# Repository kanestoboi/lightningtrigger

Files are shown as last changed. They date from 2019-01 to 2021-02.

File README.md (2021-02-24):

# Lightning Trigger

Features
* Lightning Triggering - By using a photo transistor, lightning strikes are detected and triggers the camera at the same instant.  
  
* Sound Triggering - Sound triggering mode is used to capture sound events such as water droplets, breaking glass, and fireworks.  
  
* Timelapse- Calculates the number of photos for a given length timelapse, given the photo duration, interval, and total timelapse length before taking all the required photos.  
  
Currently has support for two triggering outputs (can trigger two devices at once) with an additional two outputs being added in the next revision.  
  
Control is through an Android app using the HM-11 Bluetooth module.  
  
Power is from a li-po battery and is charged using an onboard li-po charger.

## Images

Images are located in the [Images](https://github.com/kanestoboi/lightningtrigger/tree/master/Images) directory.

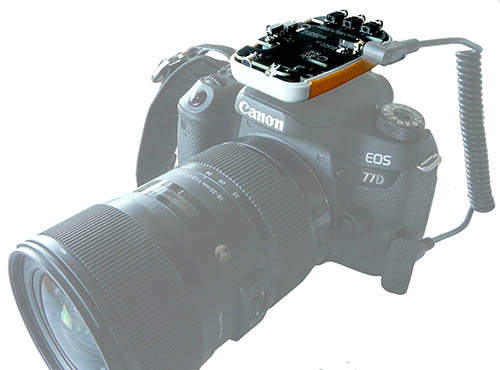
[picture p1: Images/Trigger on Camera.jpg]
Trigger with Camera


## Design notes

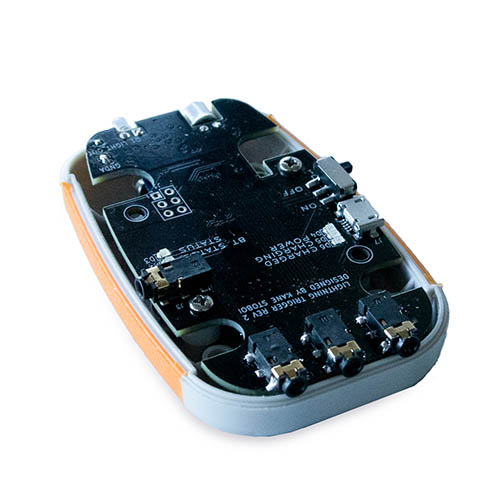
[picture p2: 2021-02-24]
Images/Trigger 2.jpg

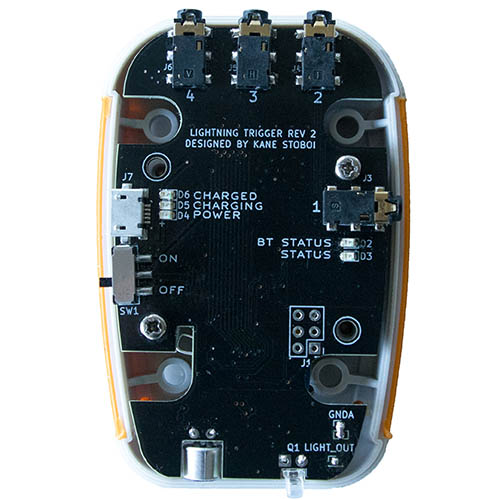
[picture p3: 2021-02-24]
Images/Trigger 1.jpg

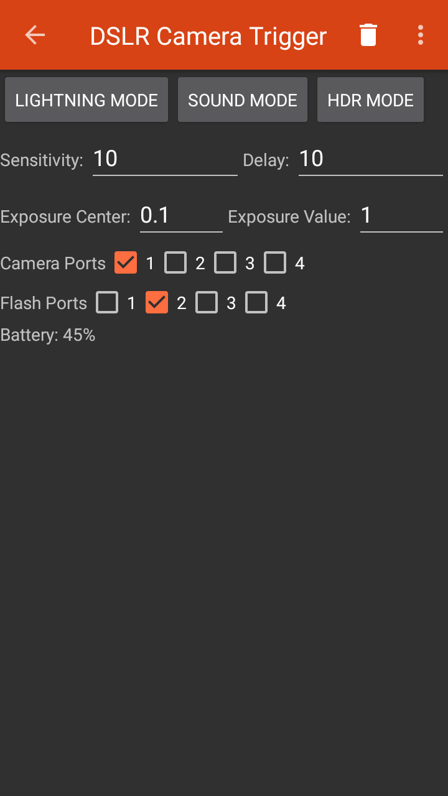
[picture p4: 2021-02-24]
Images/mobile app.png

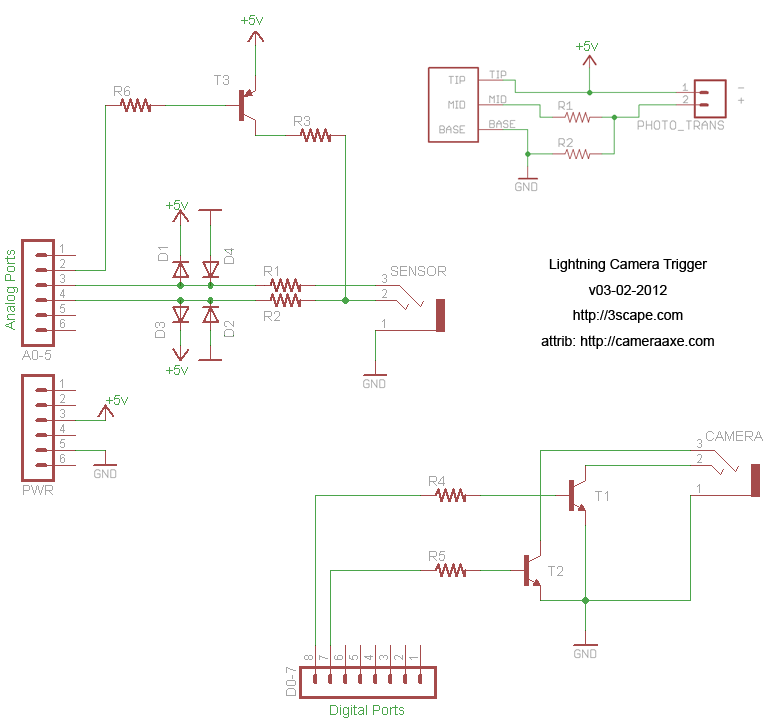
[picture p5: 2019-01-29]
Reference/circuit.png

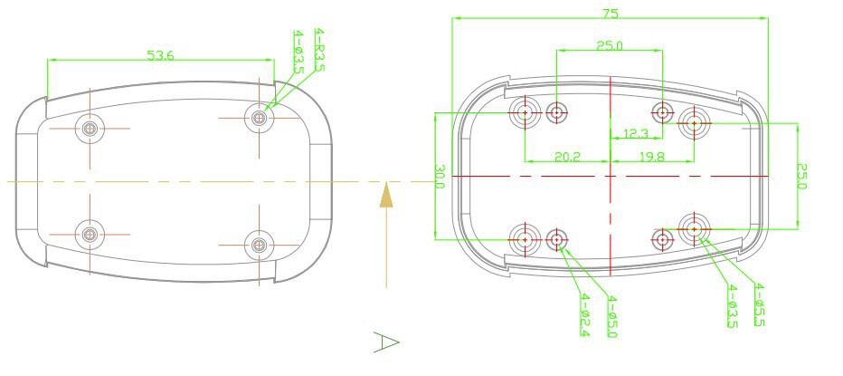
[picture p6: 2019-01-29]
Reference/Drawing1.jpg

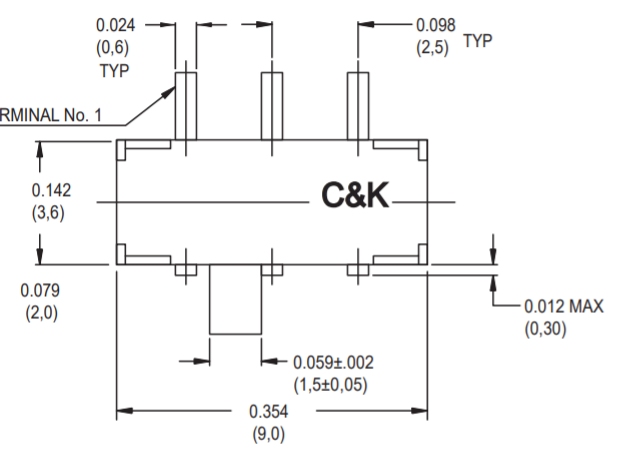
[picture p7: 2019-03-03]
Reference/switch.PNG

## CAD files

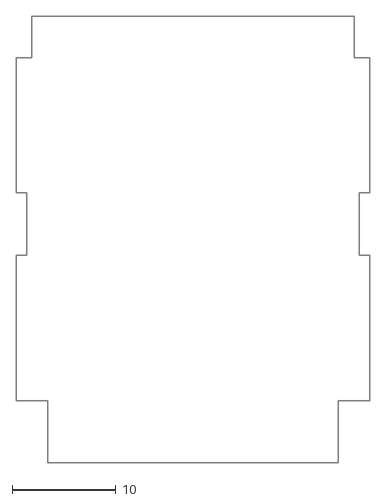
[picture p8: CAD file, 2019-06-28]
Hardware/lightning trigger Rev 3/board outline 2.dxf
34.0 x 43.0

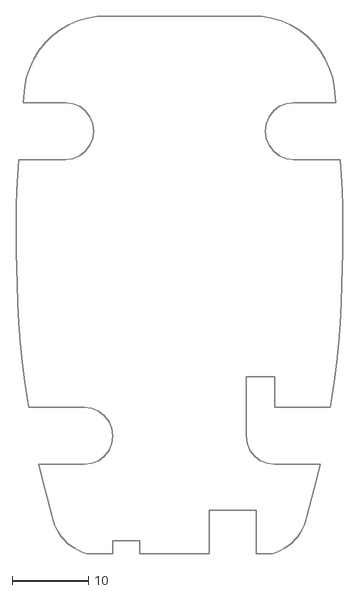
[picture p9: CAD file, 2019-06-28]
Reference/board edge cuts rev 2.dxf
42.9 x 70.5

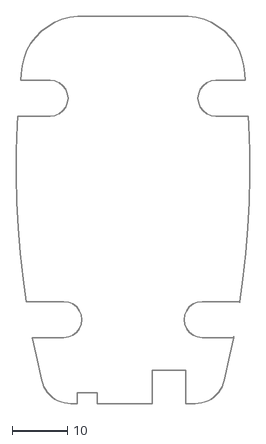
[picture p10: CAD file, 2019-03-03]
Hardware/lightning trigger Rev 3/board image.dxf
42.2 x 70.0

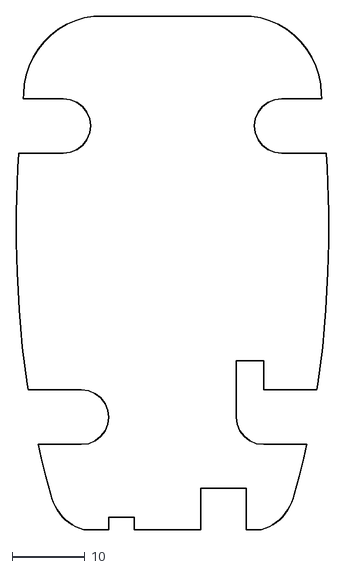
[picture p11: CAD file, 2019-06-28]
Reference/board edge cuts rev 2 R12.dxf
42.9 x 70.5

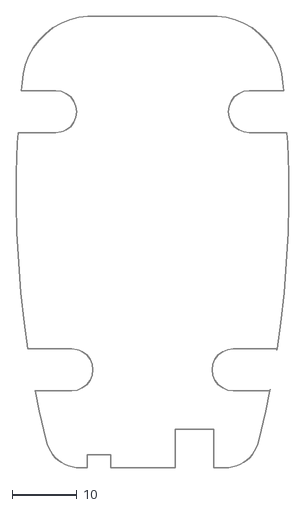
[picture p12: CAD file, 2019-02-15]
Hardware/lightning trigger Rev 3/board outline.dxf
42.2 x 70.0

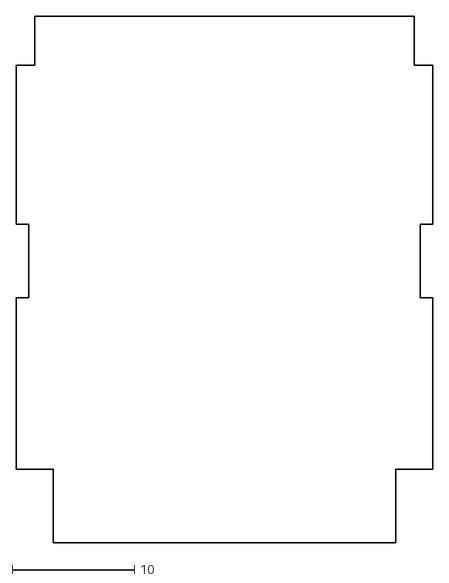
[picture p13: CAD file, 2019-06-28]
Reference/board outline R12.dxf
34.0 x 43.0

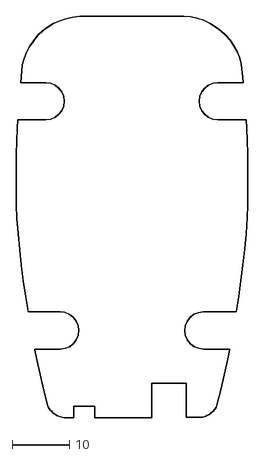
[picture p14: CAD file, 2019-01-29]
Hardware/lightning trigger Rev 3/board outline libreCAD.dxf
40.5 x 70.0

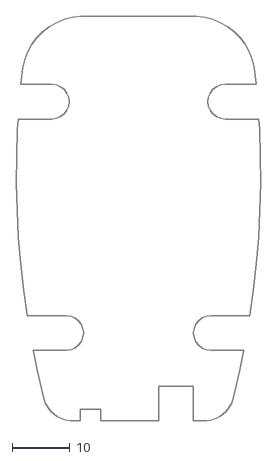
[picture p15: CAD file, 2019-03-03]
Reference/board image.dxf
42.2 x 70.0

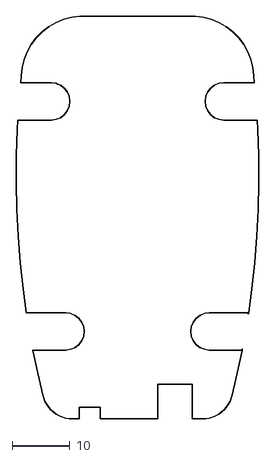
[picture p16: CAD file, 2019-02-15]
Reference/enclosure outline LibreCAD.dxf
42.2 x 70.0

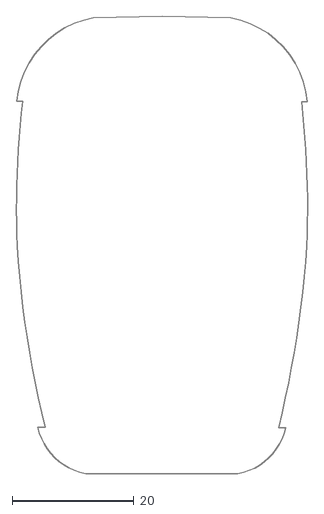
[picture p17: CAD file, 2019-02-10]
Reference/enclosure outline.dxf
47.8 x 75.0

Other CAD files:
Reference/board image.skp

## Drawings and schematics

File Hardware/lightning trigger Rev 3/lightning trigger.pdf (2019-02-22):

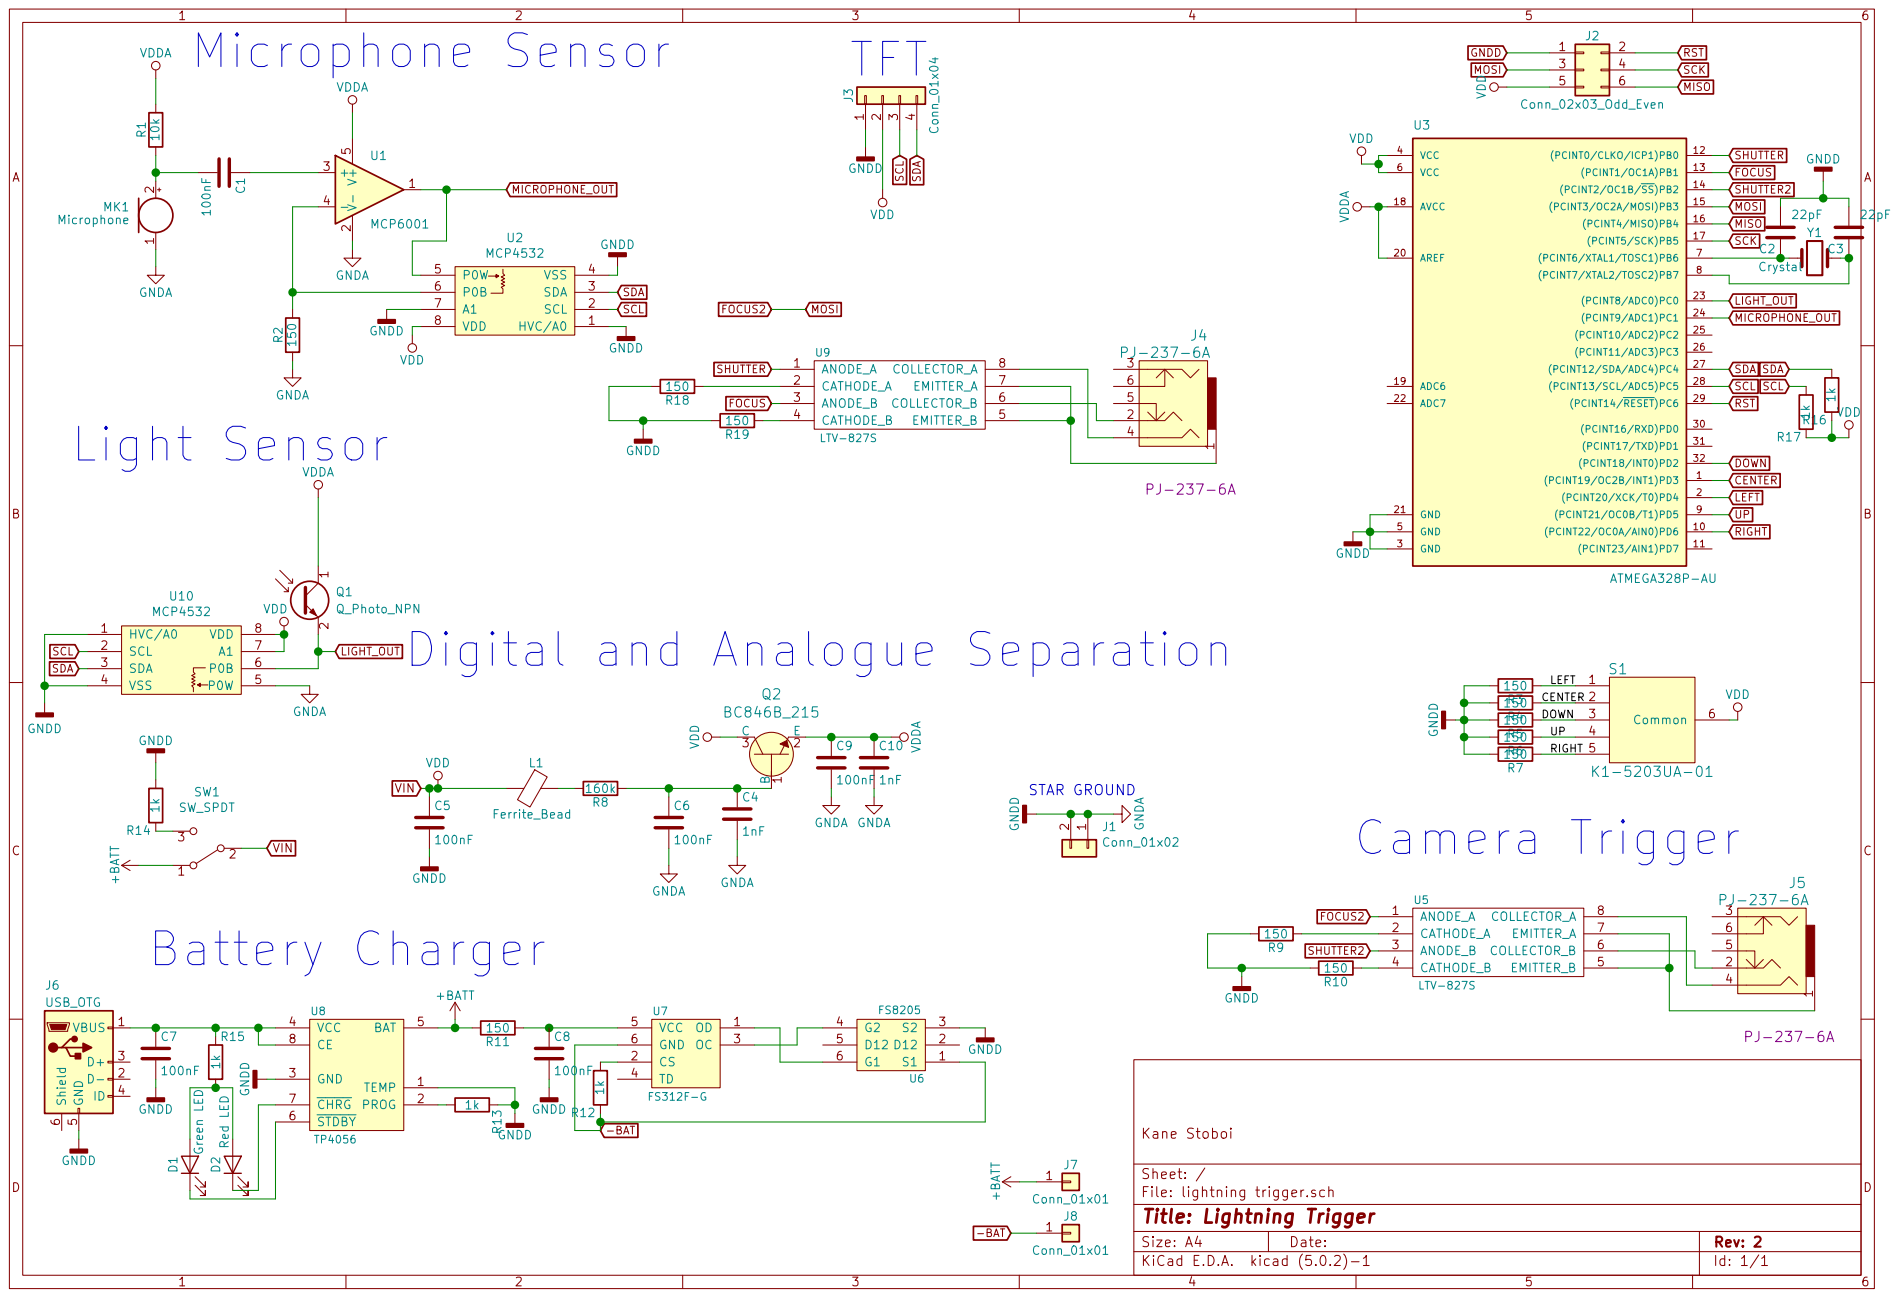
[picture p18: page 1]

LEFT RIGHT CENTER TFT

4 J3 Conn_01x04 GNDD SCL SDA GNDD

1 2 Q1Q_Photo_NPN
Digital and Analogue Separation VDD

File: lightning trigger.sch Sheet: / Kane Stoboi

Id: 1/1 Title: Lightning Trigger

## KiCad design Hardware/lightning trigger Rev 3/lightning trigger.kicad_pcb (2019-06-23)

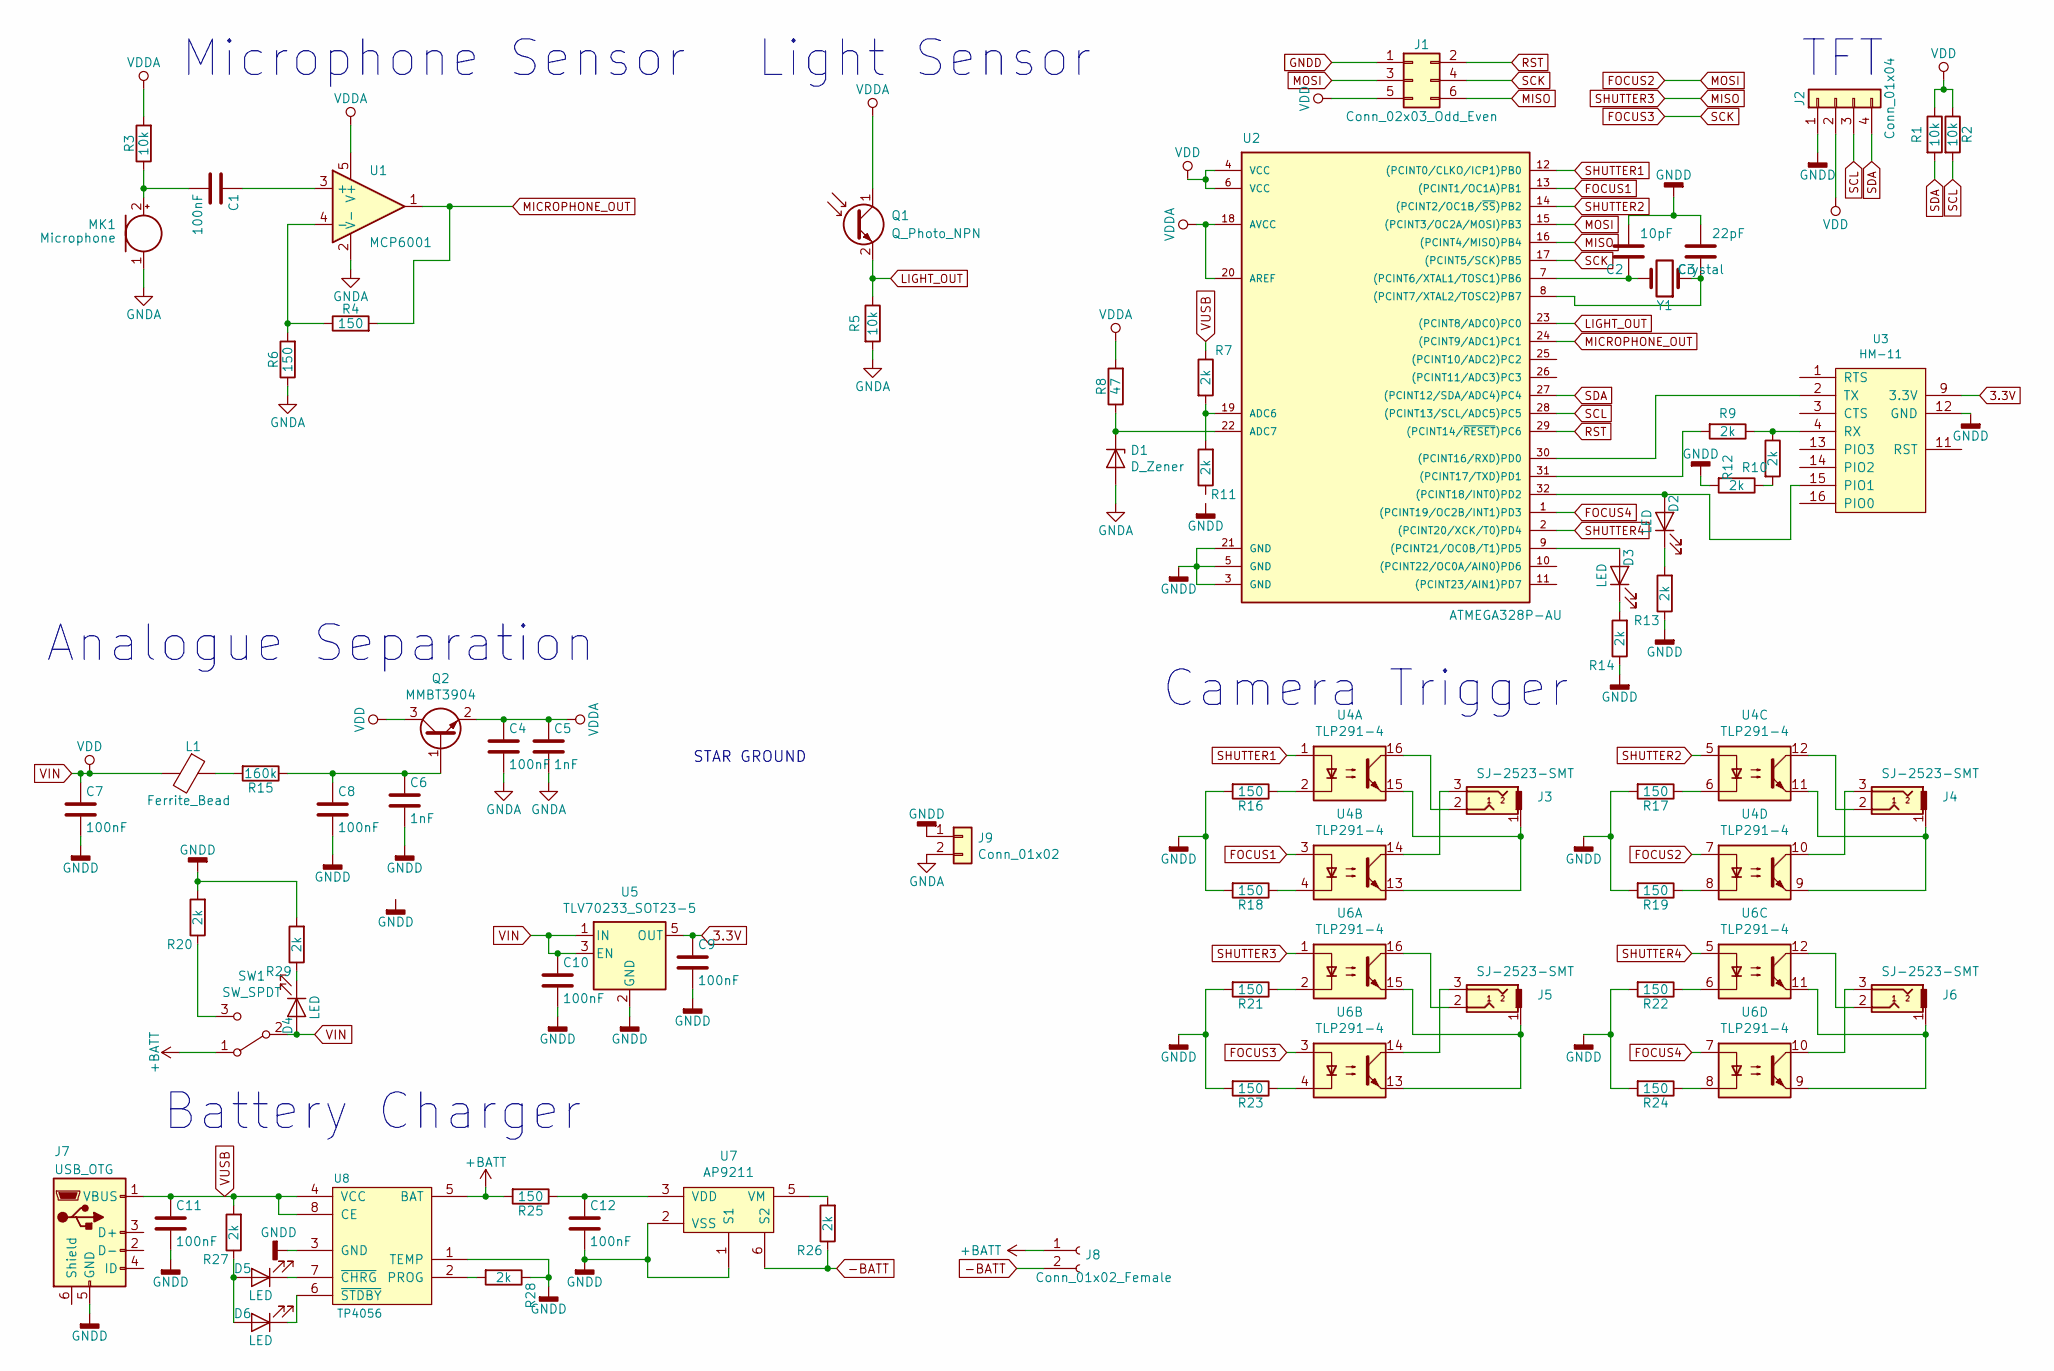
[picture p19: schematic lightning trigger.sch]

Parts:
C1, C4, C7, C8, C9, C10, C11, C12: 100nF; C_0603_1608Metric; Manufacturer Part Number C0603C104J5RACTU
C2: 10pF; C_0603_1608Metric; Manufacturer Part Number CGA3E2C0G1H100D080AA
C3: 22pF; C_0603_1608Metric; Manufacturer Part Number CGA3E2C0G1H100D080AA
C5, C6: 1nF; C_0603_1608Metric; Manufacturer Part Number C0603C102J1RACTU
D1: D_Zener; SC-90A; Manufacturer Part Number DZ2J027M0L
D2, D3, D4, D6: LED; LED_0603_1608Metric; Manufacturer Part Number LTST-C190KGKT
D5: LED; LED_0603_1608Metric; Manufacturer Part Number LTST-C190KRKT
J1: Conn_02x03_Odd_Even; Pin_Header_Straight_2x03_Pitch2.54mm
J2: Conn_01x04; Pin_Header_Straight_1x04_Pitch2.54mm
J3, J4, J5, J6: SJ-2523-SMT; Manufacturer Part Number SJ-2523-SMT
J7: USB_OTG; USB_Micro_C77238
J8: Conn_01x02_Female; JST_PH_S2B-PH-SM4-TB_1x02-1MP_P2.00mm_Horizontal; Manufacturer Part Number S2B-PH-SM4-TB
J9: Conn_01x02; R_0805_2012Metric
L1: Ferrite_Bead; C_0805_2012Metric; Manufacturer Part Number MH2029-300Y
MK1: Microphone; ELECTRET MICROPHONE
Q1: Q_Photo_NPN; LED_D3.0mm_Horizontal_O1.27mm_Z2.0mm; Manufacturer Part Number SFH 310-2/3
Q2: MMBT3904; SOT-23; Manufacturer Part Number MMBT3904LT1G
R1, R2, R3, R5: 10k; R_0603_1608Metric; Manufacturer Part Number ERJ-3GEYJ103V
R4, R6, R16, R17, R18, R19, R21, R22, R23, R24, R25: 150; R_0603_1608Metric; Manufacturer Part Number ERJ-3GEYJ151V
R7, R9, R10, R11, R12, R13, R14, R20, R26, R27, R28, R29: 2k; R_0603_1608Metric; Manufacturer Part Number ERJ-3GEYJ202V
R8: 47; R_0603_1608Metric; Manufacturer Part Number ERJ-3GEYJ470V
R15: 160k; R_0603_1608Metric; Manufacturer Part Number ERJ-3GEYJ164V
SW1: SW_SPDT; JS102011SAQN; Manufacturer Part Number JS102011SAQN
U1: MCP6001; SOT-23-5; Manufacturer Part Number MCP6001T-I/OT
U2: ATMEGA328P-AU; TQFP-32_7x7mm_Pitch0.8mm; Manufacturer Part Number ATMEGA328P-AU
U3: HM-11; Manufacturer Part Number HM-11
U4, U6: TLP291-4; SOIC-16_4.55x10.3mm_P1.27mm; Manufacturer Part Number TLP291-4(GB-TP,E)
U5: TLV70233_SOT23-5; SOT-23-5; Manufacturer Part Number TLV70233DBVR
U7: AP9211; U-DFN2030-6; Manufacturer Part Number AP9211S-AN-HAC-7
U8: TP4056; SOP-8; Manufacturer Part Number DIO5158
Y1: Crystal; Crystal_SMD_2016-4Pin_2.0x1.6mm; Manufacturer Part Number ECS-160-10-37-JTN-TR

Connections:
3.3V: C9.1, U3.9 (3.3V), U5.5 (OUT)
+BATT: J8.1, R25.2, SW1.1 (A), U8.5 (BAT)
-BATT: J8.2, R26.1, U7.6 (S2)
FOCUS1: U2.13 ((PCINT1/OC1A)PB1), U4.3
FOCUS2: J1.3, U2.15 ((PCINT3/OC2A/MOSI)PB3), U4.7
FOCUS3: J1.4, U2.17 ((PCINT5/SCK)PB5), U6.3
FOCUS4: U2.1 ((PCINT19/OC2B/INT1)PD3), U6.7
GNDA: C4.2, C5.2, D1.2 (A), J9.2, MK1.1 (-), R5.2, R6.1, U1.2 (V-); also elsewhere on the board
GNDD: C2.2, C3.2, C6.2, C7.2, C8.2, C9.2, C10.2, C11.2, C12.2, J1.1, J2.1, J7.5 (GND), J9.1, R12.2, R13.1, R14.1, R16.2, R17.2, R18.2, R19.2, R20.2, R21.2, R22.2, R23.2, R24.2, R28.1, R29.2, U2.3 (GND), U2.5 (GND), U2.21 (GND), U3.12 (GND), U5.2 (GND), U7.1 (S1), U7.2 (VSS), U8.1 (TEMP), U8.3 (GND)
LIGHT_OUT: Q1.2 (E), R5.1, U2.23 ((PCINT8/ADC0)PC0); also elsewhere on the board
MICROPHONE_OUT: R4.2, U1.1, U2.24 ((PCINT9/ADC1)PC1)
MISO: J1.6, U2.16 ((PCINT4/MISO)PB4), U6.1
unnamed: C1.1, U1.3 (+)
unnamed: C1.2, MK1.2 (+), R3.1
unnamed: C2.1, U2.7 ((PCINT6/XTAL1/TOSC1)PB6), Y1.2
unnamed: C3.1, U2.8 ((PCINT7/XTAL2/TOSC2)PB7), Y1.1
unnamed: C6.1, C8.1, Q2.1 (B), R15.1
unnamed: C12.1, R25.1, U7.3 (VDD)
unnamed: D1.1 (K), R8.1, U2.22 (ADC7)
unnamed: D2.1 (K), R13.2
unnamed: D2.2 (A), U2.32 ((PCINT18/INT0)PD2), U3.15 (PIO1)
unnamed: D3.1 (K), R14.2
unnamed: D3.2 (A), U2.9 ((PCINT21/OC0B/T1)PD5)
unnamed: D4.1 (K), R29.1
unnamed: D5.1 (K), U8.7 (~CHRG)
unnamed: D5.2 (A), D6.2 (A), R27.1
unnamed: D6.1 (K), U8.6 (~STDBY)
unnamed: J3.1, U4.13, U4.15
unnamed: J3.2, U4.16
unnamed: J3.3, U4.14
unnamed: J4.1, U4.9, U4.11
unnamed: J4.2, U4.12
unnamed: J4.3, U4.10
unnamed: J5.1, U6.13, U6.15
unnamed: J5.2, U6.16
unnamed: J5.3, U6.14
unnamed: J6.1, U6.9, U6.11
unnamed: J6.2, U6.12
unnamed: J6.3, U6.10
unnamed: L1.1, R15.2
unnamed: R4.1, R6.2, U1.4 (-)
unnamed: R9.2, U2.31 ((PCINT17/TXD)PD1)
unnamed: R9.1, R10.1, U3.4 (RX)
unnamed: R10.2, R12.1
unnamed: R7.2, R11.2, U2.19 (ADC6)
unnamed: R16.1, U4.2
unnamed: R17.1, U4.6
unnamed: R18.1, U4.4
unnamed: R19.1, U4.8
unnamed: R20.1, SW1.3 (C)
unnamed: R21.1, U6.2
unnamed: R22.1, U6.6
unnamed: R23.1, U6.4
unnamed: R24.1, U6.8
unnamed: R26.2, U7.5 (VM)
unnamed: R28.2, U8.2 (PROG)
unnamed: U2.30 ((PCINT16/RXD)PD0), U3.2 (TX)
RST: J1.2, U2.29 ((PCINT14/~RESET~)PC6)
SCL: J2.3, R2.2, U2.28 ((PCINT13/SCL/ADC5)PC5)
SDA: J2.4, R1.2, U2.27 ((PCINT12/SDA/ADC4)PC4)
SHUTTER1: U2.12 ((PCINT0/CLKO/ICP1)PB0), U4.1
SHUTTER2: U2.14 ((PCINT2/OC1B/~SS~)PB2), U4.5
SHUTTER4: U2.2 ((PCINT20/XCK/T0)PD4), U6.5
VDDA: C4.1, C5.1, Q1.1 (C), Q2.2 (E), R3.2, R8.2, U1.5 (V+), U2.18 (AVCC), U2.20 (AREF)
VIN: C7.1, C10.1, D4.2 (A), J1.5, J2.2, L1.2, Q2.3 (C), R1.1, R2.1, SW1.2 (B), U2.4 (VCC), U2.6 (VCC), U5.1 (IN), U5.3 (EN)
VUSB: C11.1, J7.1 (VBUS), R7.1, R27.2, U8.4 (VCC), U8.8 (CE)

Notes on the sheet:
Microphone Sensor
Light Sensor
Camera Trigger
TFT
Battery Charger
Analogue Separation
STAR GROUND

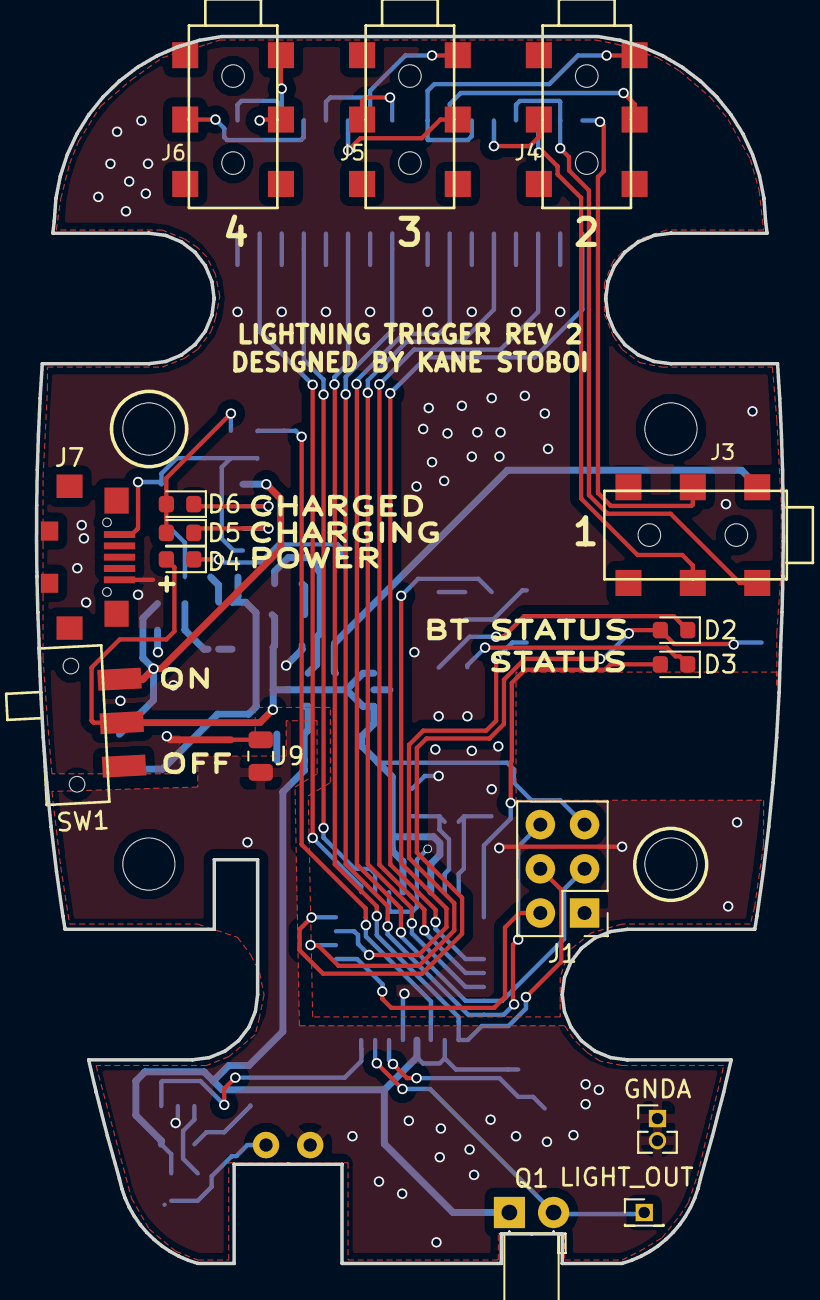
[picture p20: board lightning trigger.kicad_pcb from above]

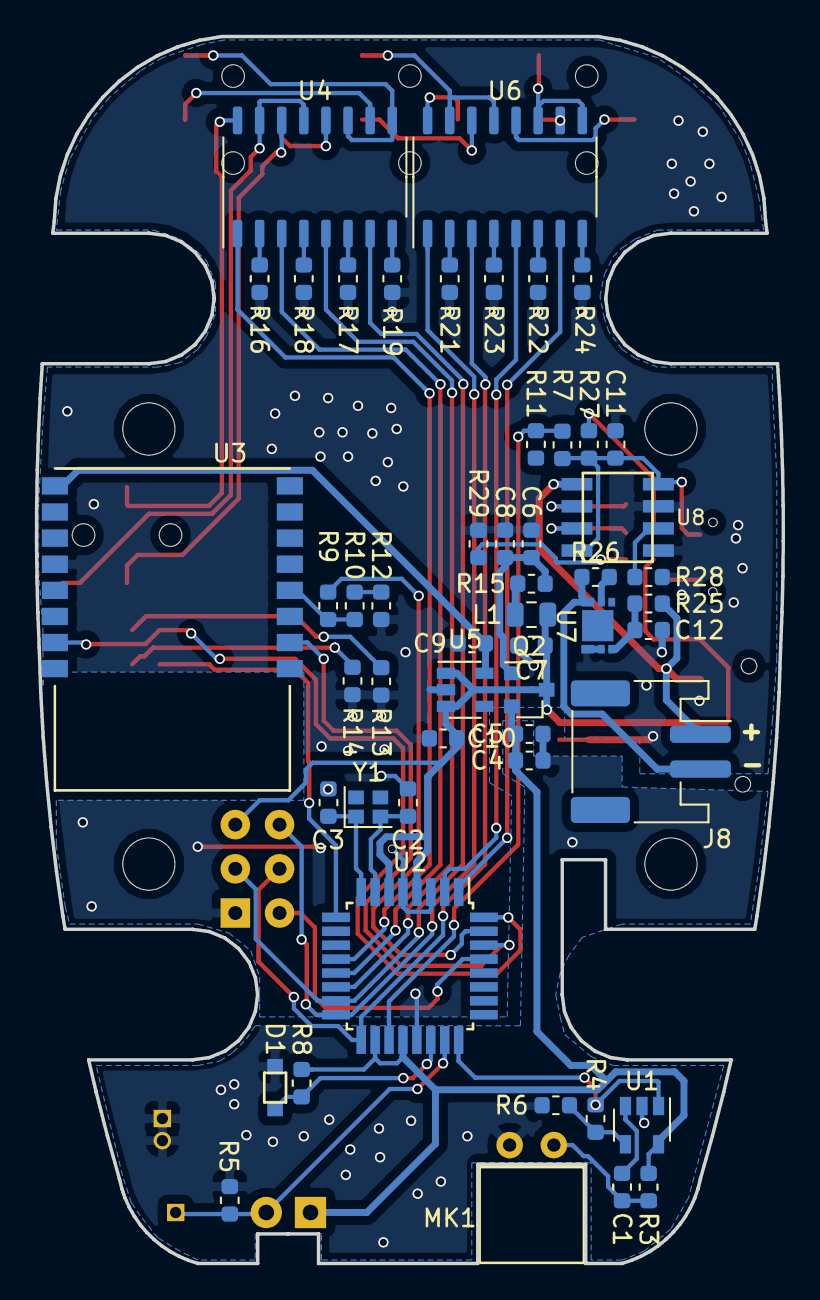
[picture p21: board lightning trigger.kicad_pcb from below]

Board: 2 copper layers, 42.9 x 70.5 mm, 68 parts (52 on the bottom side), 63 nets.

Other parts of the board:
GNDA: PinHeader_1x02_P1.27mm_Vertical
LIGHT_OUT: PinHeader_1x01_P1.27mm_Vertical

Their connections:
GNDA: GNDA.1, GNDA.2; also elsewhere on the board
LIGHT_OUT: LIGHT_OUT.1; also elsewhere on the board

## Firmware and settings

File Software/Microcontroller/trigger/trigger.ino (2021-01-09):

// Include libraries for LCD
#include <util/delay.h>


#include <SoftwareSerial.h>// import the serial library
#include <ArduinoJson.h>

#include "Timelapse.h"
#include "ThresholdTrigger.h"
#include "BatteryIndicator.h"
#include "HDR.h"


void triggerCamera();
void focusCamera();
void releaseCamera();
void triggerFlash();

volatile bool Serial_INTERRUPT_FLAG = false;
volatile bool BT_SEND_FLAG = false;

/*********************************
 * DEVELOPMENT SETUP
 ********************************/

int rx = 0;  // software serial RX pin
int tx = 1;  // software serial TX pin 
long counter = 0; // debugging counter
int statusLEDPin = 5;


/*********************************
 * CONFIGURATION SETUP
 ********************************/
/*int rx = 10;  // software serial RX pin
int tx = 11;  // software serial TX pin 
*/
#define OLED_RESET 4

#define F_CPU 16000000UL  // Define the microcontroller clock speed (16 MHz)


// Create various objects
//Adafruit_SSD1306 display(OLED_RESET);   // create LCD object
//SoftwareSerial Serial(rx, tx);       // create Serial object
Timelapse timelapse = Timelapse(&triggerCamera, &releaseCamera);
ThresholdTrigger thresholdTrigger = ThresholdTrigger(&focusCamera, &triggerCamera, &releaseCamera, &triggerFlash);
BatteryIndicator batteryIndicator = BatteryIndicator(7);
HDR hdr = HDR(&triggerCamera, &releaseCamera, &focusCamera);
StaticJsonDocument<150> SerialRxMessage;
StaticJsonDocument<150> SerialTxMessage;
DeserializationError error;

// Variables
int lightningSensitivity = 10;  // Threshold for light to trigger camera
int soundSensitivity = 10;
const char* currentMode = "";


// Various Flags


// masks used
int focus1Mask = 0b00000010;        // PORT B Mask
int shutter1Mask = 0b00000001;      // PORT B Mask
int focus2Mask = 0b00001000;        // PORT B Mask
int shutter2Mask = 0b00000100;      // PORT B Mask
int focus3Mask = 0b00100000;        // PORT B Mask
int shutter3Mask = 0b00010000;      // PORT B Mask
int focus4Mask = 0b00001000;        // PORT D Mask
int shutter4Mask = 0b00010000;      // PORT D Mask
int PORTBCameraFocusMask = 0b00000000;   // PORT B Mask
int PORTBCameraTriggerMask = 0b00000000; // PORT B Mask
int PORTBFlashTriggerMask = 0b00000000;  // PORT B Mask

int PORTDCameraFocusMask = 0b00000000;   // PORT B Mask
int PORTDCameraTriggerMask = 0b00000000; // PORT B Mask
int PORTDFlashTriggerMask = 0b00000000;  // PORT B Mask


void setup() {

  char c;
  //Serial.begin(38400);
  Serial.begin(115200);  // Begin the Serial serial and set data rate

  
/*
  Serial.print("A");
    delay(100);
    while(Serial.available())
            c = Serial.read();

    Serial.print("AT");
            delay(100);

    while(Serial.available())
            c = Serial.read();


    delay(100);

    Serial.print("AT+NAMEDSLR REMOTE");
    delay(100);
        while(Serial.available())
            c = Serial.read();

    delay(100);

    Serial.print("AT+MODE2");
    delay(100);
        while(Serial.available())
            c = Serial.read();

*/

            

            
  Serial.println("Serial connected");
  sei();

  
  /**********************************
   * THERE IS A BUG IN THE DISPLAY.BEGIN FUNCTION CAUSING PD4 TO BE SET HIGH
   * THE WORK AROUND BELOW SETS ALL PINS LOW BEFORE SETTING THEM AS INPUTS
   **********************************/
  DDRB = DDRB | 0b00111111; // set focus and shutter pins to be outputs
  DDRD = DDRD | 0b00110000;

  attachInterrupt(0,SerialISR,  RISING); // setup interrupt for INT0 (UNO pin 2) //TODO: Change this to real interrupt

  timer2InterruptSetup();

  pinMode(statusLEDPin, OUTPUT);
  digitalWrite(statusLEDPin, LOW);


}


void loop() {

  if (Serial_INTERRUPT_FLAG) {
    readSerialString();
    if (error) {
      Serial_INTERRUPT_FLAG = false;
      Serial.println("DeserializationError");
    }
    else {
      thresholdTrigger.setSensitivity(SerialRxMessage["sensitivity"]);
      thresholdTrigger.setTriggerDelay(SerialRxMessage["delay"]);
      hdr.setCenterSpeed(SerialRxMessage["exposureCenter"]);
      hdr.setExposureValue(SerialRxMessage["exposureValue"]);

      PORTBCameraFocusMask = 0b00000000;
      PORTBCameraTriggerMask = 0b00000000;
      for (int i = 0; i < SerialRxMessage["cameraPort"].size(); i++)
      {
        if (SerialRxMessage["cameraPort"][i] == 1)
        {
          PORTBCameraFocusMask |= focus1Mask;
          PORTBCameraTriggerMask |= shutter1Mask;
          
        } else if (SerialRxMessage["cameraPort"][i] == 2) {
          PORTBCameraFocusMask |= focus2Mask;
          PORTBCameraTriggerMask |= shutter2Mask;
        } else if (SerialRxMessage["cameraPort"][i] == 3) {
          PORTBCameraFocusMask |= focus3Mask;
          PORTBCameraTriggerMask |= shutter3Mask;
        } else if (SerialRxMessage["cameraPort"][i] == 4) {
          PORTDCameraFocusMask |= focus4Mask;
          PORTDCameraTriggerMask |= shutter4Mask;
        }
      }

      PORTBFlashTriggerMask = 0b00000000;
      PORTDFlashTriggerMask &= 0b11001111;
      for (int i = 0; i < SerialRxMessage["flashPort"].size(); i++)
      {
        if (SerialRxMessage["flashPort"][i] == 1)
        {
          PORTBFlashTriggerMask |= focus1Mask;
          PORTBFlashTriggerMask |= shutter1Mask;
        } else if (SerialRxMessage["flashPort"][i] == 2) {
          PORTBFlashTriggerMask |= focus2Mask;
          PORTBFlashTriggerMask |= shutter2Mask;
        } else if (SerialRxMessage["flashPort"][i] == 3) {
          PORTBFlashTriggerMask |= focus3Mask;
          PORTBFlashTriggerMask |= shutter3Mask;
        } else if (SerialRxMessage["flashPort"][i] == 4) {
          PORTDFlashTriggerMask |= focus4Mask;
          PORTDFlashTriggerMask |= shutter4Mask;
        }
      }

      currentMode = SerialRxMessage["mode"];
      sendAsyncInfo();

      if (SerialRxMessage["mode"] == "tm") {  // if the run time-lapse command was received from phone
        Serial_INTERRUPT_FLAG = false;
        digitalWrite(statusLEDPin, HIGH);
        timelapseMode();
      }
      else if (SerialRxMessage["mode"] == "sm") {  // if the run sound mode command was received from phone
        Serial_INTERRUPT_FLAG = false;
        digitalWrite(statusLEDPin, HIGH);
        soundMode();  
      }
      else if (SerialRxMessage["mode"] == "lm") {  // if the run lightning mode command was received from phone
        Serial_INTERRUPT_FLAG = false;
        digitalWrite(statusLEDPin, HIGH);
        lightningMode();
      }
      else if (SerialRxMessage["mode"] == "hdr") {  // if the run HDR mode command was received from phone
        Serial_INTERRUPT_FLAG = false;
        digitalWrite(statusLEDPin, HIGH);
        hdrMode();
      }
      else if (SerialRxMessage["mode"] == "ss") {  // if the run single shot mode command was received from phone
        Serial_INTERRUPT_FLAG = false;
        digitalWrite(statusLEDPin, HIGH);
        singleShotMode();        
      }
      else {
        Serial_INTERRUPT_FLAG = false;
      }

      digitalWrite(statusLEDPin, LOW);

      currentMode = "";   
    }
  }  
}

void SerialISR(){
  Serial_INTERRUPT_FLAG = true; // trigger flag indicating a SerialRxMessage was received 
  digitalWrite(statusLEDPin, HIGH);
}

void setupSoundMode() {
  thresholdTrigger.setADCInput(1);
  thresholdTrigger.setup();
  thresholdTrigger.reset();
}

void setupLightningMode() {
  thresholdTrigger.setADCInput(0); // Set multiplexer to 0
  thresholdTrigger.setup();
  thresholdTrigger.reset();
}

static void focusCamera() {
  PORTB |= PORTBCameraFocusMask;  // focus the camera  
  PORTD |= PORTDCameraFocusMask;  // focus the camera
}

static void triggerCamera() {
  PORTB |= PORTBCameraTriggerMask;  // trigger the outputs
  PORTD |= PORTDCameraTriggerMask;  
}

static void releaseCamera() {
  PORTB &= ~(PORTBCameraFocusMask | PORTBCameraTriggerMask);   // reset camera outputs to off
  PORTD &= ~(PORTDCameraFocusMask | PORTDCameraTriggerMask);
}

void triggerFlash() {
  PORTB |= PORTBFlashTriggerMask;  // trigger the outputs
  PORTD |= PORTDFlashTriggerMask;  // trigger the outputs
  _delay_ms(200);
  PORTB &= ~PORTBFlashTriggerMask;   // reset trigger outputs to off
  PORTD &= ~PORTDFlashTriggerMask;   // reset trigger outputs to off
}

void lightningMode() {  
  setupLightningMode();
  Serial.println("Lightning Mode");
  Serial_INTERRUPT_FLAG = false; //TODO: need to find out why Serial flag is being triggered from above line

  thresholdTrigger.setSensitivity(SerialRxMessage["sensitivity"]); 

  thresholdTrigger.resetCalibration();
  ADCSRA |= B01000000;
  while(!thresholdTrigger.isCalibrated())
    thresholdTrigger.calibrateThreshold();

  Serial.println("Calibrated  Lightning Mode");

  ADCSRA |= B01000000;
  thresholdTrigger.focusCamera();
  counter = 0;
  int triggers = 0;
  while(1) {
    if (triggers < thresholdTrigger.getNumberOfTriggers()){
      Serial.print("Number of Triggers: ");
      Serial.println(thresholdTrigger.getNumberOfTriggers());
      triggers = thresholdTrigger.getNumberOfTriggers();
    }
    thresholdTrigger.run();
    
    if (Serial_INTERRUPT_FLAG) {
      thresholdTrigger.end();
      Serial.println("Exiting Lightning Mode");
      return;
    }
  }
}

void soundMode() {
  setupSoundMode();
  Serial.println("Sound Mode");


  thresholdTrigger.resetCalibration();
  ADCSRA |= B01000000;
  while(!thresholdTrigger.isCalibrated())
    thresholdTrigger.calibrateThreshold();

  Serial.println("Waiting for Sound");
  thresholdTrigger.triggerCamera();
  delay(1000);
  
  Serial_INTERRUPT_FLAG = false;
  while(!thresholdTrigger.run()) {
    if (Serial_INTERRUPT_FLAG) {
      thresholdTrigger.end();
      Serial.println("Exiting Sound Mode");
      return;
              
    }
  }
  thresholdTrigger.end();
  Serial.println("Sound Triggered");  
}

void timelapseMode() {
  
  Serial.write("Timelapse Mode");
  Serial_INTERRUPT_FLAG = false;   //TODO: need to find out why Serial flag is being triggered from above line
  timelapse.reset();

  timelapse.setExposure(SerialRxMessage["exposure"]);
  timelapse.setTotalPhotos(SerialRxMessage["photos"]);
  timelapse.setDelayBetweenShots(SerialRxMessage["delay"]);
  
  int lastPhotoTaken = -1;
  
  while (!timelapse.isDone()) {
    timelapse.run();

    if (lastPhotoTaken < timelapse.getPhotosTaken()) {
      SerialTxMessage["photosTaken"] = timelapse.getPhotosTaken();
      SerialTxMessage["totalPhotos"] = timelapse.getTotalPhotos();
      lastPhotoTaken = timelapse.getPhotosTaken();
      while (BT_SEND_FLAG);
      sendAsyncInfo();
    }


    if (Serial_INTERRUPT_FLAG) {
      readSerialString();
      if (SerialRxMessage["flag"] == "err") {  // if the eit time-lapse command was received from phone
        timelapse.end();
        Serial_INTERRUPT_FLAG = false;
        break;
      }
      Serial_INTERRUPT_FLAG = false; // reset interrupt flag
    }
  }
  
  if (timelapse.isDone()) {
    while (BT_SEND_FLAG); // wait until previous BT message has been sent
    sendAsyncInfo();
  }
  else 
    Serial.write("Exited");

  SerialTxMessage.remove("photosTaken");
  SerialTxMessage.remove("totalPhotos");
}

void hdrMode() {
  Serial.println("HDR Mode");
  Serial_INTERRUPT_FLAG = false;

  hdr.setPhotoTimeExposures();

  Serial.println("Running HDR");

  hdr.reset();

  delay(2000);
  while (!hdr.isDone()) {
    hdr.run();
  }
  Serial.println("HDR Done");
}

void singleShotMode() {

  if (SerialRxMessage["timed"] == false)
  {
    triggerCamera();
    _delay_ms(200);
    releaseCamera();
  }
  else {
    //statusLEDDoubleFlash();
    long startMillis = millis();
    long timerDelay = SerialRxMessage["delay"];
    triggerCamera();
    while((millis() - startMillis) < timerDelay) {
      if (Serial_INTERRUPT_FLAG) {
        readSerialString();
        if (SerialRxMessage["flag"] == "err") {  // if the eit time-lapse command was received from phone
          Serial_INTERRUPT_FLAG = false;
          break;
        }
        Serial_INTERRUPT_FLAG = false; // reset interrupt flag
      }
    }
    releaseCamera();
  }
  

}

void readSerialString() {
  String incommingMessage = ""; //clears variable for new input
  char c = ' ';
  while (c != '}') {
    // TODO: Add timeout timer for this
    if(Serial.available()) {
      c = Serial.read();  //gets one byte from serial buffer
      incommingMessage += c; 

      if (c == '}') {
        break;
      }  //breaks out of capture loop to print readstring
    } //makes the string readString  
  }

  if (incommingMessage.length() >0) {
    error = deserializeJson(SerialRxMessage, incommingMessage);

    if (error) {
      //Serial.write(F("deserializeJson() failed: "));
      //Serial.println(error.c_str());
      return;
    }
  }

  digitalWrite(statusLEDPin, LOW);
}

void timer2InterruptSetup() {
  TCCR1A = 0;// set entire TCCR1A register to 0
  TCCR1B = 0;// same for TCCR1B
  TCNT1  = 0;//initialize counter value to 0
  // set compare match register for 1hz increments
  OCR1A = 65535;// = (16*10^6) / (1*1024) - 1 (must be <65536)
  // turn on CTC mode
  TCCR1B |= (1 << WGM12);
  // Set CS12 and CS10 bits for 1024 prescaler
  TCCR1B |= (1 << CS12) | (1 << CS10);  
  // enable timer compare interrupt
  TIMSK1 |= (1 << OCIE1A);
}

/**********************************
 * OVERFLOW TIMER RUNS "ASYNCHRONOUS" CODE EVERY 4 SECONDS
 **********************************/
ISR(TIMER1_COMPA_vect) { //timer1 interrupt 4Hz 

  sendAsyncInfo();
}

void sendAsyncInfo() {

  if (BT_SEND_FLAG)
    return;

  int admuxHolder = ADMUX;
  int adcsraHolder = ADCSRA;
  int adcsrbHolder = ADCSRB;
  String output;
  SerialTxMessage["batteryLevel"] = batteryIndicator.getBatteryLevelPercentage();
  SerialTxMessage["batteryStatus"] = batteryIndicator.getBatteryStatus();
  SerialTxMessage["currentMode"] = currentMode;

  //
  serializeJson(SerialTxMessage, output);

  BT_SEND_FLAG = true;
  Serial.println(output);
  BT_SEND_FLAG = false;

  ADMUX = admuxHolder;
  ADCSRA = adcsraHolder;
  ADCSRB = adcsrbHolder;
  ADCSRA |= B01000000;  // kick off next ADC 
}

void statusLEDDoubleFlash() {
  digitalWrite(statusLEDPin, HIGH);
  _delay_ms(300);
  digitalWrite(statusLEDPin, LOW);
  _delay_ms(300);
  digitalWrite(statusLEDPin, HIGH);
  _delay_ms(300);
  digitalWrite(statusLEDPin, LOW);

}

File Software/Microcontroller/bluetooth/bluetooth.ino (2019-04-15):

#include <SoftwareSerial.h>// import the serial library

int rx = 10;  // software serial RX pin
int tx = 11;  // software serial TX pin
volatile bool interruptFlag = false;
volatile char message;

SoftwareSerial Bluetooth(10, 11); // RX, TX

void setup() {
  Bluetooth.begin(9600);  // Begin the bluetooth serial and set data rate
  Bluetooth.println("Bluetooth connected");

  Serial.begin(9600);

  attachInterrupt(0,bluetoothISR,  RISING); // setup interrupt for INT0 (UNO pin 2)
}

void loop() {
  // if the ISR has been triggered print the message to the hardware serial
  if (interruptFlag) {
    Serial.println(message);
    interruptFlag = false;  // clear the interrupt trigger flag
  }
}

void bluetoothISR(){
  interruptFlag = true; // trigger flag indicating a message was received 
  message = Bluetooth.read();  // read the messgage
}

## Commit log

2019-01-29 added to-to and tasks
    [tasks.xlsx]
2019-01-29 added more tasks to list
    [tasks.xlsx]
2019-02-10 added enclosure outline to pcb layout
    [enclosure outline LibreCAD.dxf, enclosure outline.dxf]
2019-02-15 added compliance testing to tasks
    [tasks.xlsx]
2019-02-15 re-drew board outline to make it larger
    [board image.skp, board outline.dxf, lightning trigger.kicad_pcb]
2019-02-15 updated BOM details for parts
    [lightning trigger.sch]
2019-02-15 updated footprints for new KiCAD library
2019-02-22 created pdf of schematic
2019-03-02 added trigger comparisons
    [feature-comparison.xlsx]
2019-03-02 updated progress
    [tasks.xlsx]
2019-03-02 refactored ADC conversion code
2019-03-03 added state machine for menu system. Software is ready for testing on prototype
2019-03-03 more updates to task progress
    [tasks.xlsx]
2019-03-03 restructured hardware files for new revision
    [board image.dxf, board outline libreCAD.dxf, board outline.dxf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]
2019-03-09 fixed bug that would restrict ADC sampling rate (| when setting ADCSRA), added basic calibration of threshold, fixed address of digital potentiometers,
    [trigger.ino]
2019-03-09 added more things to fix after working with first revision prototype
2019-03-17 cleaning up calibration each time an ADC is read
2019-04-11 calibrating each time there is a trigger
2019-04-12 sound mode now configured to trigger flash and have camera in bulb mode.
2019-04-13 updating resistors and capacitors to be macrofab house parts
    [lightning trigger.sch]
2019-04-13 more schematic updates with new components
    [lightning trigger.sch]
2019-04-15 creating simple bluetooth example using an interrupt to check for a message
2019-04-18 added battery monitor circuitry, and power mux for switching between charging and battery power
    [lightning trigger.sch]
2019-04-18 more schematic updates for power mux
    [lightning trigger.sch]
2019-04-20 cleaning up arduino code after thresholdTrigger addition
2019-04-21 added BatteryInicator class to monitor battery level
2019-04-21 only add unique bluetooth devices to list
2019-04-22 fixed bug in BatteryIndicator class causing the ADC registers to not be set the same as they were before battery ADC conversion
    [BatteryIndicator.cpp, trigger.ino]
2019-04-22 updating tasks
    [tasks.xlsx]
2019-04-22 added logic conversion for HM-11 RX module
    [lightning trigger.sch]
2019-04-23 more additions to sound trigger. Fixed bug in ThresholdTrigger.setup() causing ADCMUX to always be set to input 0
    [ThresholdTrigger.cpp, trigger.ino]
2019-04-26 more changes to rev 2 schematic
    [lightning trigger.sch]
2019-04-26 focus camera when in lightning mode
2019-06-23 Finished revision 2 of board layout
    [board image.skp, lightning trigger.kicad_pcb, lightning trigger.sch]
2019-06-28 new board outline
    [board outline 2.dxf]
2019-06-28 adding support for charging indicator
2019-06-28 set camera to be focused ready for next photo
2019-06-28 updates to support rev 2 board
2019-06-28 new board outline files
    [board edge cuts rev 2 R12.dxf, board edge cuts rev 2.dxf, board outline R12.dxf]
2019-06-28 removing gerbers from git
    [lightning trigger-B.SilkS.gbr, lightning trigger-Edge.Cuts.gbr, lightning trigger-F.Cu.gbr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]
2019-06-28 moving directory to rev 3
    [board image.dxf, board outline 2.dxf, board outline libreCAD.dxf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]
2019-07-21 removed old hardware sensitivity adjustment and Wire code. Added some basic status LED indications when modes are entered and exited.
2019-07-21 optimising DFM. removed 150 ohm resistors and replaced with 2k that are already in use. Added hardware to reset uC from HM-11. Fixed BATT- and GND issue with AP9211 that was causing the battery to st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
    [lightning trigger.sch]
2019-09-13 added single shot mode and fixed bug causing currentMode variable to become null. (made variable const char*)
    [trigger.ino]
